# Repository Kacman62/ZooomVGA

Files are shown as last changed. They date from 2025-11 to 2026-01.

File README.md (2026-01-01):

# ZooomVGA
An STM32 dev board complete with VGA out

Untitled design(5)

# The Idea

I've been spending a lot of time on software recently and I wanted to do another hardware project. After browsing the Hack CLub slack, I saw there was a zoom call for Blueprint, the hardware program and I decided to join in. The theme was a Trace Race, where you try to make a board in the shortest amount of time. Just an hour before I saw a [VGA library](https://github.com/RoCorbera/BlueVGA) for the exact same STM32 module in the challenge and I knew what my proejct was going to be. The schematic was pretty quick to put together, using a USB C port, an ASM power regulator, the STM32F103C8, a Crystal Oscillator and the VGA port. After getting it reviewed by Kai, and improving it a little bit I moved onto the board in about an hour and a half. The board was a little harder, the VGA port is bigger than the width of a breadboard so I had to flange it out a little. But after aligning everything I started routing the pins. This was a lot harder, I put the MCU off center to get both the USB lines and the crystal to be close to it, but this caused the left side to be very cramped and a pain to route. After 2 hours of painful routing, and another half hour of polish, I finished the entire board in 4 hours. I decided on the name ZooomVGA because this is the fastest I've designed a project, and it was created mainly on the Zoom call.



# The rest of the Owl

I then created a Logo for the board, imporoved the silkscreen, added my logo and exported it to JLCPCB, coming in at around $15 with the stencil and shipping. 
While making the BOM i noticed a slight error with the VGA port, so I changed it to a female connector, did some minor rerouting and fixed the error. The rest of the components are from JLCPCB and cost $20, for a $35 total (slightly lower for me, becuase I ahve LEDS, Resistors, and Capacitors, but should be very similar for you)







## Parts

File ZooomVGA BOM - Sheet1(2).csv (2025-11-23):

Part Name | Company | Link | Price per 1 | Order amount | Subtotal | Running total
PCB and Stencil | JLCPCB | https://github.com/Kacman62/ZooomVGA/blob/main/ZooomVGA%20Gerber.zip | 16.16 | 1 | 16.16 | 16.16
STM32F103C8 | LCSC | https://www.lcsc.com/product-detail/C8734.html?s_z=n_STM32F103C8 | 1.13 | 1 | 1.13 | 17.29
USBC | LCSC | https://www.lcsc.com/product-detail/C165948.html?s_z=n_TYPE-C-31-M-12 | 0.175 | 5 | 0.875 | 18.165
AMS1117 | LCSC | https://www.lcsc.com/product-detail/C6186.html?s_z=n_AMS1117 | 0.1641 | 5 | 0.8205 | 18.9855
22Ohm Resistor | LCSC | https://www.lcsc.com/product-detail/C107701.html?s_z=n_22%2520ohm | 0.0012 | 100 | 0.12 | 19.1055
330 Ohm Resistor | LCSC | https://www.lcsc.com/product-detail/C105881.html?s_z=n_330%2520Ohm | 0.0012 | 100 | 0.12 | 19.2255
Crystal Oscillator | LCSC | https://www.lcsc.com/product-detail/C13738.html?s_z=n_X322516MLB4SI | 0.0663 | 10 | 0.663 | 19.8885
VGA Femal Connector | LCSC | https://www.lcsc.com/product-detail/C3121412.html?utm_source=chatgpt.com | 1.69 | 1 | 1.69 | 21.5785
LCSC Shipping and fees |  |  |  |  | 11.78 | 33.3585
JLCPCB Fees (not shipping) |  |  |  |  | 0.9 | 34.2585
 |  |  |  |  |  | 36 | My Total
10u, .1u capacitors
100k, 10k, 5.1k 1k resistors
Leds
 |  |  |  |  |  | basically 36 dollars | Your total

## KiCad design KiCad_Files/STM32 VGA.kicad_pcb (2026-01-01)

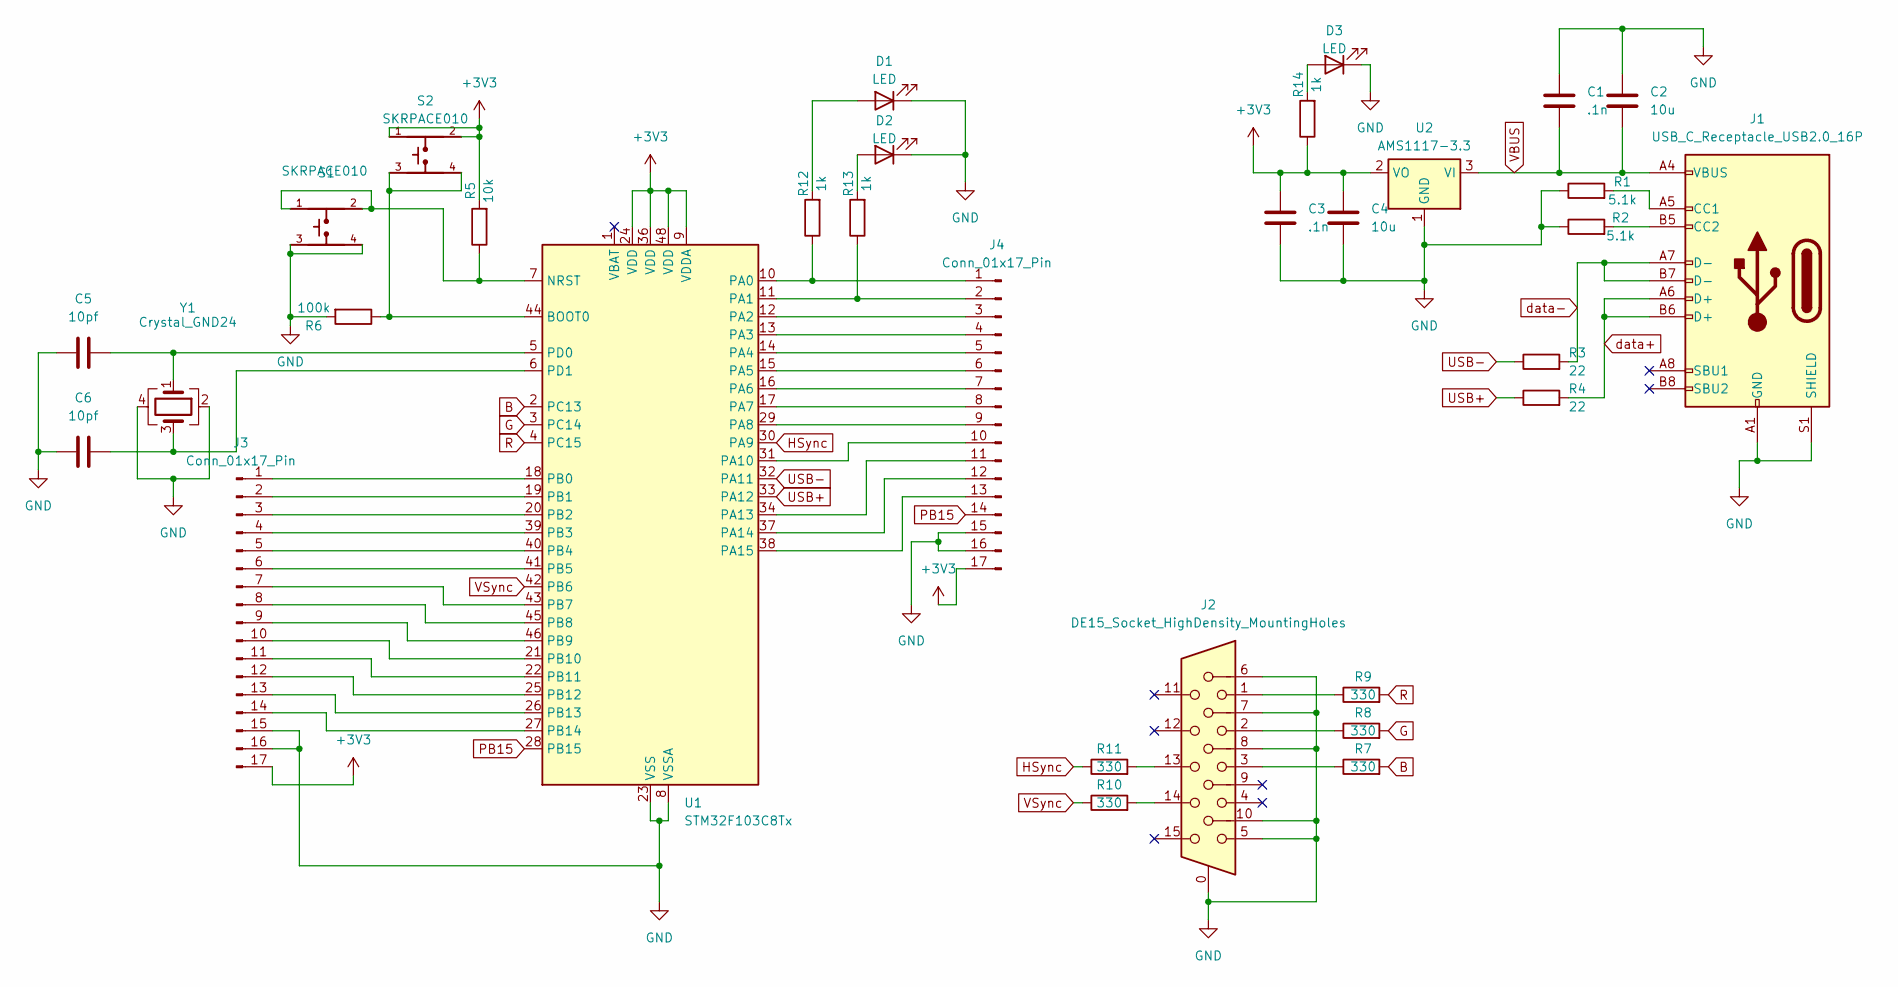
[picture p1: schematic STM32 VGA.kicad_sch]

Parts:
C1, C3: .1n; C_0603_1608Metric
C2, C4: 10u; C_0603_1608Metric
C5, C6: 10pf; C_0603_1608Metric
D1, D2, D3: LED; LED_0603_1608Metric
J1: USB_C_Receptacle_USB2.0_16P; Edited_HRO_TYPE-C-31-M-12
J2: DE15_Socket_HighDensity_MountingHoles; DSUB-15-HD_Socket_Horizontal_P2.29x1.90mm_EdgePinOffset3.03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
J3, J4: Conn_01x17_Pin; PinSocket_1x17_P2.54mm_Vertical
R1, R2: 5.1k; R_0603_1608Metric
R3, R4: 22; R_0603_1608Metric
R5: 10k; R_0603_1608Metric
R6: 100k; R_0603_1608Metric
R7, R8, R9, R10, R11: 330; R_0603_1608Metric
R12, R13, R14: 1k; R_0603_1608Metric
S1, S2: SKRPACE010; SW_SKRPACE010
U1: STM32F103C8Tx; LQFP-48_7x7mm_P0.5mm
U2: AMS1117-3.3; SOT-223-3_TabPin2
Y1: Crystal_GND24; SMD3225

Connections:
+3V3: C3.1, C4.1, J3.17, J4.17, R5.2, R14.1, S2.1, S2.2, U1.9 (VDDA), U1.24 (VDD), U1.36 (VDD), U1.48 (VDD), U2.2 (VO); also elsewhere on the board
B: R7.2, U1.2 (PC13)
G: R8.2, U1.3 (PC14)
GND: C1.1, C2.1, C3.2, C4.2, C5.1, C6.1, D1.1 (K), D2.1 (K), D3.1 (K), J1.A1 (GND), J1.A12 (GND), J1.B1 (GND), J1.B12 (GND), J1.S1 (SHIELD), J2.0, J2.5, J2.6, J2.7, J2.8, J2.10, J3.15, J3.16, J4.15, J4.16, R1.1, R2.1, R6.2, S1.3, S1.4, U1.8 (VSSA), U1.23 (VSS), U1.35 (VSS), U1.47 (VSS), U2.1 (GND), Y1.2, Y1.4; also elsewhere on the board
HSync: R11.1, U1.30 (PA9)
unnamed: D1.2 (A), R12.2
unnamed: D2.2 (A), R13.2
unnamed: D3.2 (A), R14.2
unnamed: J1.A5 (CC1), R1.2
unnamed: J1.B5 (CC2), R2.2
unnamed: J2.1, R9.1
unnamed: J2.2, R8.1
unnamed: J2.3, R7.1
unnamed: J2.13, R11.2
unnamed: J2.14, R10.2
unnamed: J3.1, U1.18 (PB0)
unnamed: J3.2, U1.19 (PB1)
unnamed: J3.3, U1.20 (PB2)
unnamed: J3.4, U1.39 (PB3)
unnamed: J3.5, U1.40 (PB4)
unnamed: J3.6, U1.41 (PB5)
unnamed: J3.7, U1.43 (PB7)
unnamed: J3.8, U1.45 (PB8)
unnamed: J3.9, U1.46 (PB9)
unnamed: J3.10, U1.21 (PB10)
unnamed: J3.11, U1.22 (PB11)
unnamed: J3.12, U1.25 (PB12)
unnamed: J3.13, U1.26 (PB13)
unnamed: J3.14, U1.27 (PB14)
unnamed: J4.1, R12.1, U1.10 (PA0)
unnamed: J4.2, R13.1, U1.11 (PA1)
unnamed: J4.3, U1.12 (PA2)
unnamed: J4.4, U1.13 (PA3)
unnamed: J4.5, U1.14 (PA4)
unnamed: J4.6, U1.15 (PA5)
unnamed: J4.7, U1.16 (PA6)
unnamed: J4.8, U1.17 (PA7)
unnamed: J4.9, U1.29 (PA8)
unnamed: J4.10, U1.31 (PA10)
unnamed: J4.11, U1.34 (PA13)
unnamed: J4.12, U1.37 (PA14)
unnamed: J4.13, U1.38 (PA15)
unnamed 42: R6.1, S2.3, S2.4, U1.44 (BOOT0); also elsewhere on the board
unnamed 43: R5.1, S1.1, S1.2, U1.7 (NRST); also elsewhere on the board
unnamed: C5.2, U1.5 (PD0), Y1.1
unnamed: C6.2, U1.6 (PD1), Y1.3
PB15: J4.14, U1.28 (PB15)
R: R9.2, U1.4 (PC15)
USB+: R4.1, U1.33 (PA12)
USB-: R3.1, U1.32 (PA11)
VBUS: C1.2, C2.2, J1.A4 (VBUS), J1.A9 (VBUS), J1.B4 (VBUS), J1.B9 (VBUS), U2.3 (VI)
VSync: R10.1, U1.42 (PB6)
data+: J1.A6 (D+), J1.B6 (D+), R4.2
data-: J1.A7 (D-), J1.B7 (D-), R3.2

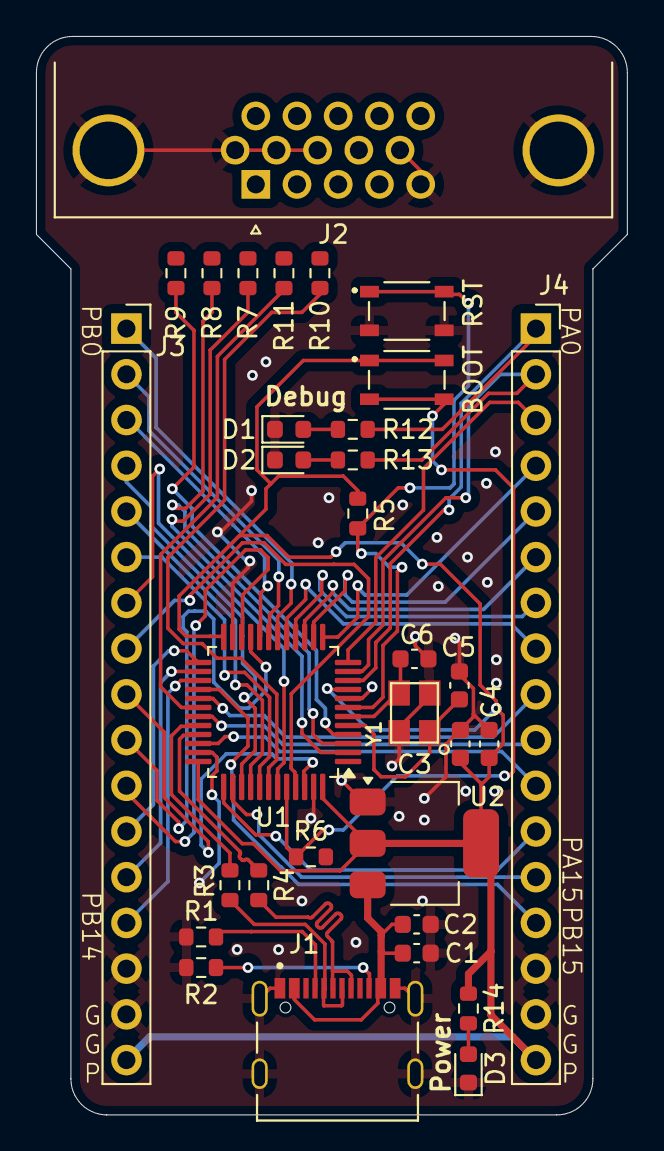
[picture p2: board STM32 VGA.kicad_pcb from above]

Board: 2 copper layers, 32.8 x 59.9 mm, 32 parts (0 on the bottom side), 54 nets.

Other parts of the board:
BOOT: SKRPACE010; SW_SKRPACE010
RST: SKRPACE010; SW_SKRPACE010

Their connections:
+3V3: BOOT.1, BOOT.2; also elsewhere on the board
GND: RST.3, RST.4; also elsewhere on the board
unnamed 42: BOOT.3, BOOT.4; also elsewhere on the board
unnamed 43: RST.1, RST.2; also elsewhere on the board

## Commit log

2025-11-23 Update README with VGA port correction details
    Corrected the VGA port to a female connector and made minor rerouting adjustments.
2026-01-01 Updated to V1.2 Schematics and PCB
    [STM32 VGA.kicad_pcb, STM32 VGA.kicad_sch]
